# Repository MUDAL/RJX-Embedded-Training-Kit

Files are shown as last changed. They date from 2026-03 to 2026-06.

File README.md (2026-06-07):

# RJX Embedded Training Kit

## Overview  

Hardware training platform built around **STM32L431** with:
- **5 V input** and dual **3.3 V rails** (digital +3V3 and analog +3V3A)
- **Li-ion charger/power-path** + **fuel gauge**
- Sensors (I2C/SMBus + SPI), UI peripherals (LCD/7-seg/buzzer), and **CAN**

This repository contains the complete **KiCad 9** hardware design, PDFs/datasheets, and the STM32CubeMX pinout file. I have ensured that it is properly version-controlled by removing unnecessary KiCad artefacts/tool-specific outputs which can easily be re-generated by any user, and ensuring transition from the schematic design to PCB design and vice-versa without using netlists. The block diagram of the project is shown in the image below.   

<p align="center">
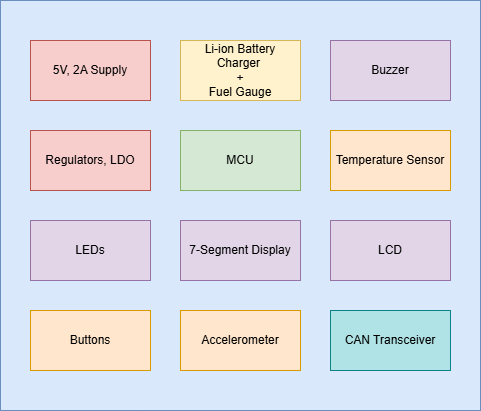
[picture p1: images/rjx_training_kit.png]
    
</p>  

---

## Repository layout

```text
.
├── LICENSE
├── README.md
├── images
│   └── rjx_training_kit.png
├── pinout
│   └── pinout.ioc
└── rjx_training_kit
    ├── Docs         (schematic PDF, datasheets, links)
    ├── Hardware     (KiCad project: schematics + PCB)
    ├── Libs         (project libraries)
    └── Outputs      (manufacturing files)
```

---

## Quick start

### View / edit hardware (KiCad 9)
1. Install **KiCad v9** (recommended).
2. Open the project:
   - `rjx_training_kit/Hardware/rjx_training_kit.kicad_pro`
3. Schematic sheets:
   - Top-level: `rjx_training_kit/Hardware/rjx_training_kit.kicad_sch`
   - Sub-sheets: `rjx_training_kit/Hardware/microcontroller.kicad_sch`, `rjx_training_kit/Hardware/peripherals.kicad_sch`
4. PCB layout:
   - `rjx_training_kit/Hardware/rjx_training_kit.kicad_pcb`

### View pin configuration (STM32CubeMX)
- Open `pinout/pinout.ioc` in **STM32CubeMX**.

---

## Documentation

### Schematic PDF
- `rjx_training_kit/Docs/rjx_training_kit.pdf`

### Component datasheets
Datasheets used by the design are stored in:
- `rjx_training_kit/Docs/`

### External links
External forum references and troubleshooting links are maintained here:
- [Links.md](rjx_training_kit/Docs/Links.md)

---

## Checklist

- [x] Schematic capture  
- [ ] Board setup  
- [ ] Component placement and routing  
- [ ] DRC  
- [ ] Generate manufacturing outputs and BOM   
- [ ] Place an order for the board on PCBWay  
- [ ] Preliminary board tests  
- [ ] Create a basic user guide on how to get started with the board  

## License
GPL-3.0 (see `LICENSE`).

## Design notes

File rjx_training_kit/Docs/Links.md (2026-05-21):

# RJX Training Kit – External Reference Links

This file collects external links (forums, app notes, etc.) so the main README stays concise.

---

## Battery charger (BQ24072/BQ24074) – TI E2E forum threads

1. **Problems in BQ24072**  
   https://e2e.ti.com/support/power-management-group/power-management/f/power-management-forum/106873/problems-in-bq24072

2. **BQ24072: Short circuit condition**  
   https://e2e.ti.com/support/power-management-group/power-management/f/power-management-forum/1271063/bq24072-short-circuit-condition

3. **BQ24072 – low battery behaviour**  
   https://e2e.ti.com/support/power-management-group/power-management/f/power-management-forum/247653/bq24072---low-battery-behaviour

4. **BQ24072 – about battery discharge**  
   https://e2e.ti.com/support/power-management-group/power-management/f/power-management-forum/647933/bq24072-about-battery-discharge-of-bq24072

5. **BQ24072: Charger without battery**  
   https://e2e.ti.com/support/power-management-group/power-management/f/power-management-forum/873241/bq24072-charger-without-battery

6. **BQ24072 – battery removed**  
   https://e2e.ti.com/support/power-management-group/power-management/f/power-management-forum/1407863/bq24072-bq24072---battery-removed

7. **BQ24074: Safety timer**  
   https://e2e.ti.com/support/power-management-group/power-management/f/power-management-forum/1430800/bq24074-safty-timer

8. **BQ24074: Safety timer**  
   https://e2e.ti.com/support/power-management-group/power-management/f/power-management-forum/787195/bq24074-safety-timer

9. **BQ24072 – current setting calculations**  
   https://e2e.ti.com/support/power-management-group/power-management/f/power-management-forum/393015/bq24072---current-setting-calculations

10. **BQ24072 – input current set is 1.5 A, charging current is set to 0.4 A**  
    https://e2e.ti.com/support/power-management-group/power-management/f/power-management-forum/685457/bq24072-input-current-set-is-1-5amps-charging-current-is-set-to-0-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

11. **BQ24072 – setting current limit**  
    https://e2e.ti.com/support/power-management-group/power-management/f/power-management-forum/65275/bq24072---setting-current-limit

---

## LDO / power-good (PG)

12. **ST forum – Power good (PG) pin on LD39100** *(related discussion for PG behavior)*  
    https://community.st.com/t5/power-management/power-good-pg-pin-on-ld39100/td-p/641594

---

## Extra resources  

13. **Electronics StackExchange - Difference between crystal oscillators and resonators**  
   https://electronics.stackexchange.com/questions/36308/crystals-oscillators-and-resonators-what-the-difference/36321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

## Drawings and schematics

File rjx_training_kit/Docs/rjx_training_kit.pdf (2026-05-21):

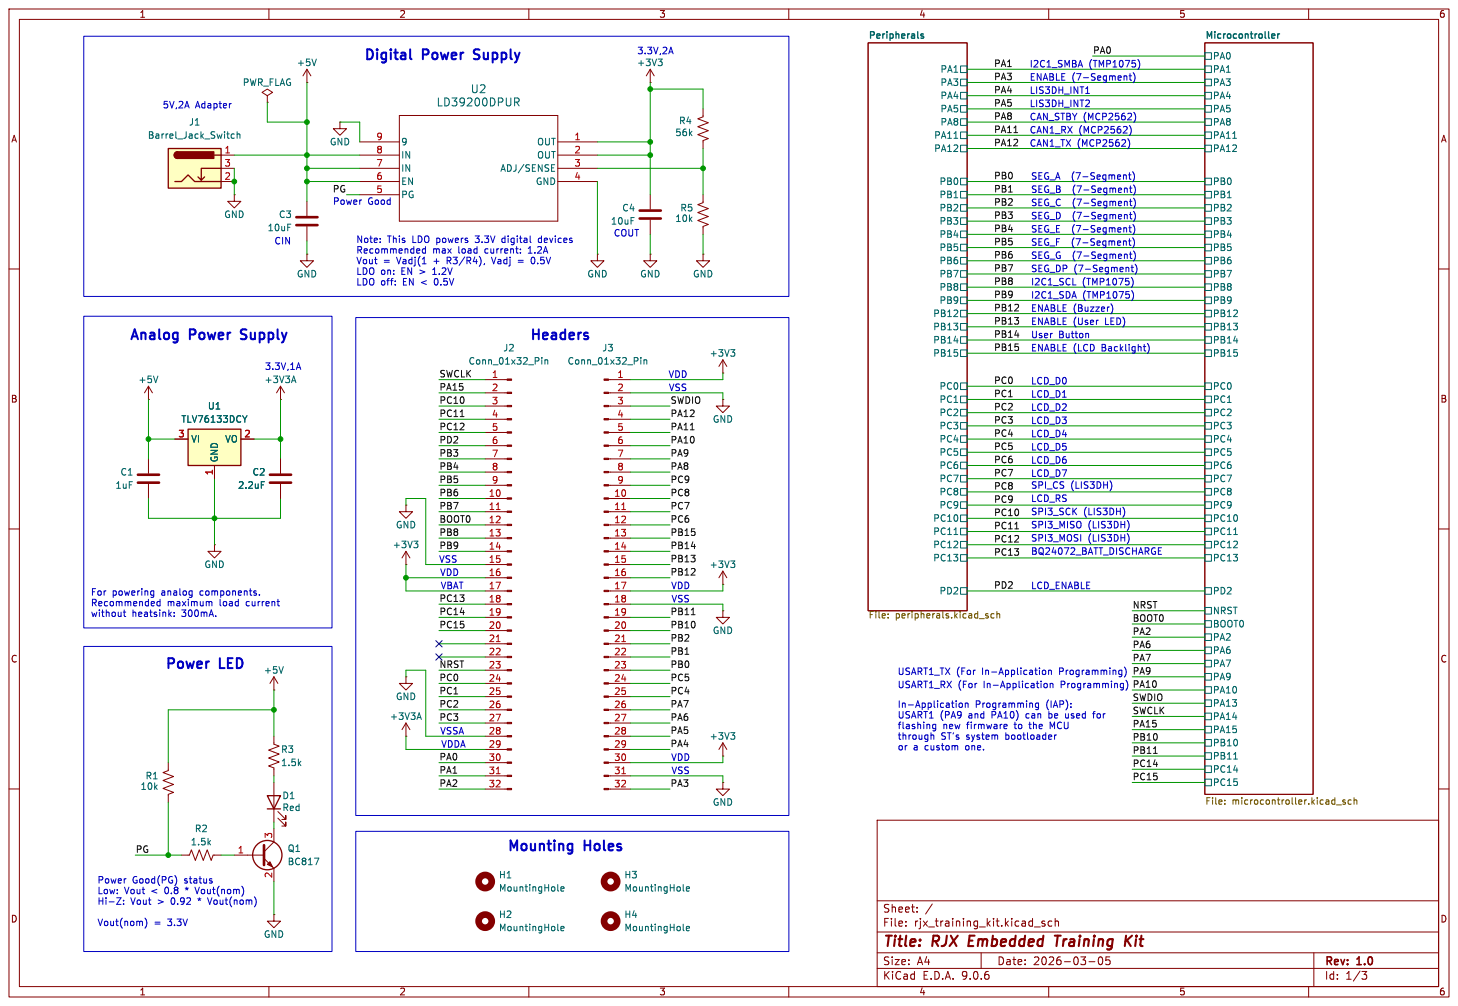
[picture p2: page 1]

LCD_D3 ENABLE (LCD Backlight) User Button

Id: 1/3 Title: RJX Embedded Training Kit File: rjx_training_kit.kicad_sch Sheet: /

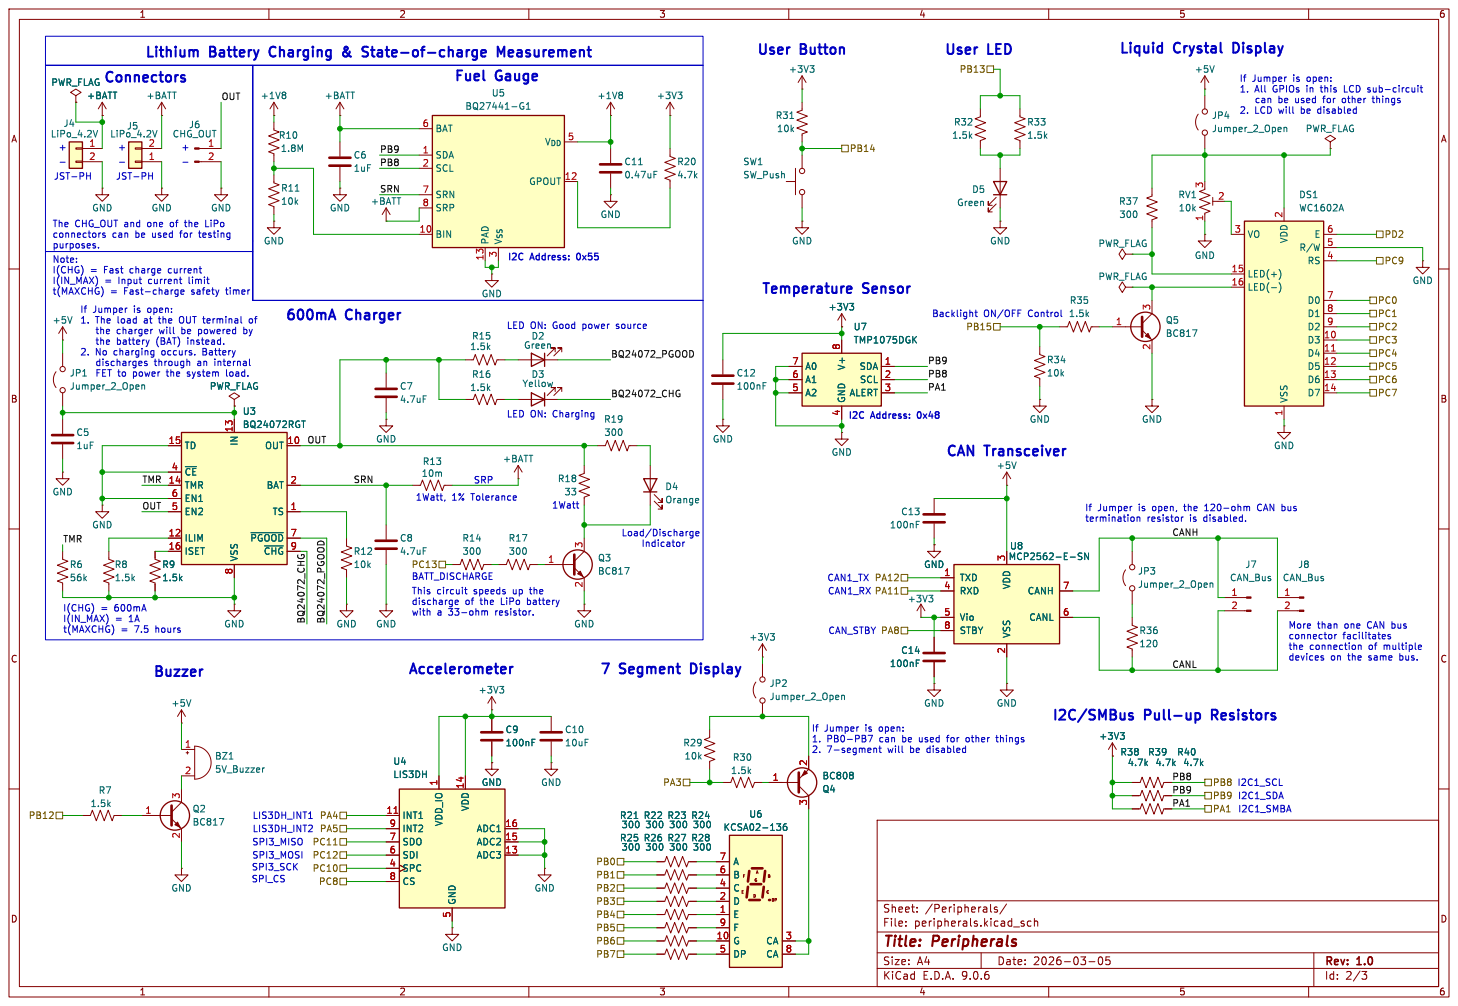
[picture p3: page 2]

Fuel Gauge
If Jumper is open: 1. All GPIOs in this LCD sub-circuit can be used for other things 2. LCD will be disabled SRP

The CHG_OUT and one of the LiPo
I(CHG) = Fast charge current
I(IN_MAX) = Input current limit

4 SDA 1 SCL 2 ALERT 3 U7 TMP1075DGK R7
the charger will be powered by

LED ON: Good power source BATT_DISCHARGE

8 OUT 10 BAT 2 TS 1 ~{PGOOD}7 ~{CHG}9 U3BQ24072RGT PWR_FLAG

8 OUT 10 BAT 2 TS 1 ~{PGOOD}7 ~{CHG}9 PWR_FLAG

File: peripherals.kicad_sch Sheet: /Peripherals/ GND

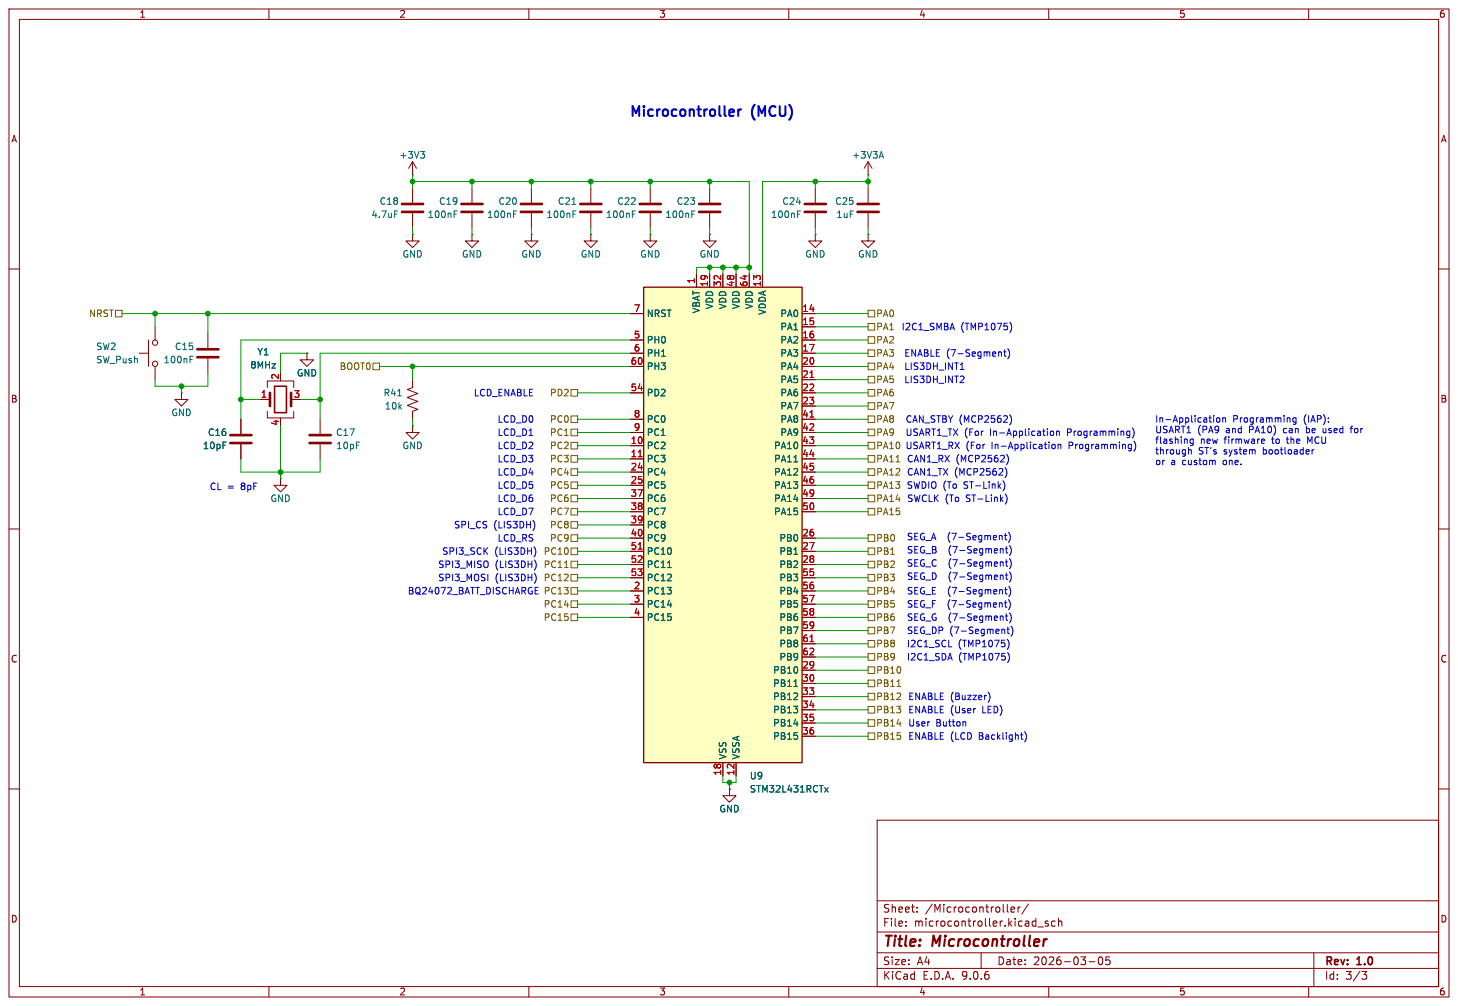
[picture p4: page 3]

I2C1_SCL (TMP1075) ENABLE (LCD Backlight) ENABLE (Buzzer) ENABLE (User LED) ENABLE (7-Segment)

1 VDD 19 VDD 32 VSS 18 VDD 48 VSSA 12 VDD 64 VDDA 13 PA0 14 PA1 15 PA2 16 PA3 17 PA4 20 PA5 21 PA6 22 PA7 23 PA8 41 PA9 42 PA10 43 PA11 44 PA12 45 PA13 46 PA14 49 PA15 50 PB0 26 PB1 27 PB2 28 PB3 55 PB4 56 PB5 57 PB6 58 PB7 59 PB8 61 PB9 62 PB10 29 PB11 30 PB12 33 PB13 34 PB14 35 PB15 36 C16

1 VDD 19 VDD 32 VSS 18 VDD 48 VSSA 12 VDD 64 VDDA 13 PA0 14 PA1 15 PA2 16 PA3 17 PA4 20 PA5 21 PA6 22 PA7 23 PA8 41 PA9 42 PA10 43 PA11 44 PA12 45 PA13 46 PA14 49 PA15 50 PB0 26 PB1 27 PB2 28 PB3 55 PB4 56 PB5 57 PB6 58 PB7 59 PB8 61 PB9 62 PB10 29 PB11 30 PB12 33 PB13 34 PB14 35 PB15 36 U9STM32L431RCTx

I2C1_SMBA (TMP1075) SWDIO (To ST-Link) SPI3_MOSI (LIS3DH) SPI3_SCK (LIS3DH) BQ24072_BATT_DISCHARGE

Id: 3/3 Title: Microcontroller File: microcontroller.kicad_sch Sheet: /Microcontroller/ GND

through ST's system bootloader or a custom one.

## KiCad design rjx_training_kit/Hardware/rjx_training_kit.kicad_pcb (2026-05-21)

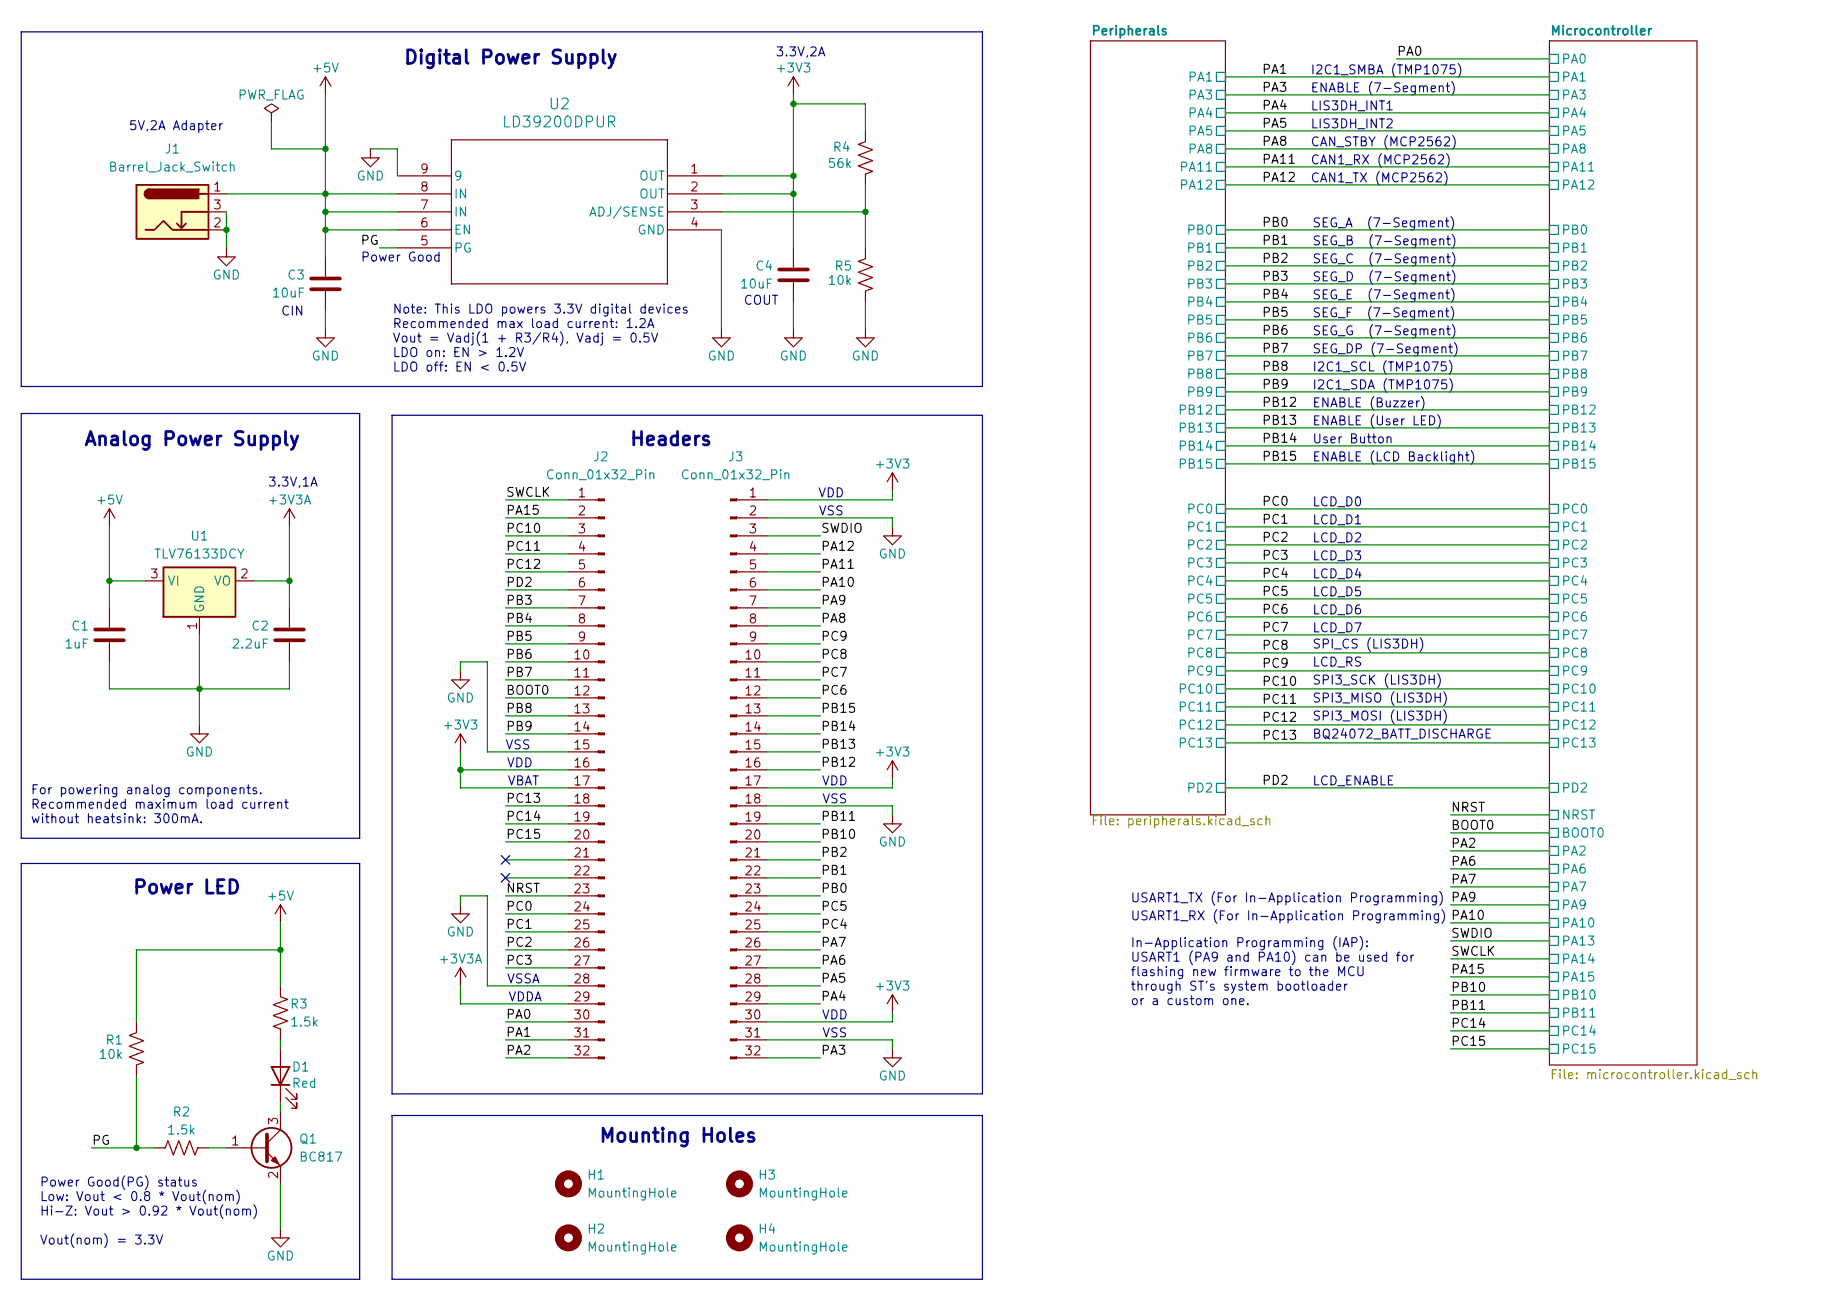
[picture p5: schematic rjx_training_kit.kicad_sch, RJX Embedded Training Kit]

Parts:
C1: 1uF; C_0603_1608Metric
C2: 2.2uF; C_0603_1608Metric
C3, C4: 10uF; C_0603_1608Metric
D1: Red; LED_0603_1608Metric
H1, H2, H3, H4: MountingHole; MountingHole_3mm
J1: Barrel_Jack_Switch; BarrelJack_Horizontal
J2, J3: Conn_01x32_Pin; PinHeader_1x32_P2.54mm_Vertical
Q1: BC817; SOT-23
R1, R5: 10k; R_0603_1608Metric
R2, R3: 1.5k; R_0603_1608Metric
R4: 56k; R_0603_1608Metric
U1: TLV76133DCY; SOT-223-3_TabPin2
U2: LD39200DPUR; DFN-8-1EP_4x4mm_P0.8mm_EP2.3x3.24mm

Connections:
+3V3: C4.1, J2.16, J2.17, J3.1, J3.17, J3.30, R4.2, U2.1 (OUT), U2.2 (OUT); also elsewhere on the board
+3V3A: C2.1, J2.29, U1.2 (VO); also elsewhere on the board
+5V: C1.1, C3.1, J1.1, R1.2, R3.1, U1.3 (VI), U2.6 (EN), U2.7 (IN), U2.8 (IN); also elsewhere on the board
/BOOT0: J2.12; also elsewhere on the board
/NRST: J2.23; also elsewhere on the board
/PA0: J2.30; also elsewhere on the board
/PA1: J2.31; also elsewhere on the board
/PA2: J2.32; also elsewhere on the board
/PA3: J3.32; also elsewhere on the board
/PA4: J3.29; also elsewhere on the board
/PA5: J3.28; also elsewhere on the board
/PA6: J3.27; also elsewhere on the board
/PA7: J3.26; also elsewhere on the board
/PA8: J3.8; also elsewhere on the board
/PA9: J3.7; also elsewhere on the board
/PA10: J3.6; also elsewhere on the board
/PA11: J3.5; also elsewhere on the board
/PA12: J3.4; also elsewhere on the board
/PA15: J2.2; also elsewhere on the board
/PB0: J3.23; also elsewhere on the board
/PB1: J3.22; also elsewhere on the board
/PB2: J3.21; also elsewhere on the board
/PB3: J2.7; also elsewhere on the board
/PB4: J2.8; also elsewhere on the board
/PB5: J2.9; also elsewhere on the board
/PB6: J2.10; also elsewhere on the board
/PB7: J2.11; also elsewhere on the board
/PB8: J2.13; also elsewhere on the board
/PB9: J2.14; also elsewhere on the board
/PB10: J3.20; also elsewhere on the board
/PB11: J3.19; also elsewhere on the board
/PB12: J3.16; also elsewhere on the board
/PB13: J3.15; also elsewhere on the board
/PB14: J3.14; also elsewhere on the board
/PB15: J3.13; also elsewhere on the board
/PC0: J2.24; also elsewhere on the board
/PC1: J2.25; also elsewhere on the board
/PC2: J2.26; also elsewhere on the board
/PC3: J2.27; also elsewhere on the board
/PC4: J3.25; also elsewhere on the board
/PC5: J3.24; also elsewhere on the board
/PC6: J3.12; also elsewhere on the board
/PC7: J3.11; also elsewhere on the board
/PC8: J3.10; also elsewhere on the board
/PC9: J3.9; also elsewhere on the board
/PC10: J2.3; also elsewhere on the board
/PC11: J2.4; also elsewhere on the board
/PC12: J2.5; also elsewhere on the board
/PC13: J2.18; also elsewhere on the board
/PC14: J2.19; also elsewhere on the board
/PC15: J2.20; also elsewhere on the board
/PD2: J2.6; also elsewhere on the board
/PG: R1.1, R2.1, U2.5 (PG)
/SWCLK: J2.1; also elsewhere on the board
/SWDIO: J3.3; also elsewhere on the board
GND: C1.2, C2.2, C3.2, C4.2, J1.2, J1.3, J2.15, J2.28, J3.2, J3.18, J3.31, Q1.2 (E), R5.1, U1.1 (GND), U2.4 (GND), U2.9; also elsewhere on the board
unnamed: D1.2 (A), R3.2
unnamed: D1.1 (K), Q1.3 (C)
unnamed: Q1.1 (B), R2.2
unnamed: R4.1, R5.2, U2.3 (ADJ/SENSE)

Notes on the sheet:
SPI3_SCK (LIS3DH)
For powering analog components. Recommended maximum load current without heatsink: 300mA.
Mounting Holes
SEG_C (7-Segment)
COUT
VSS
Power Good(PG) status Low: Vout < 0.8 * Vout(nom) Hi-Z: Vout > 0.92 * Vout(nom) Vout(nom) = 3.3V
CAN_STBY (MCP2562)
I2C1_SDA (TMP1075)
ENABLE (7-Segment)
SEG_B (7-Segment)
Analog Power Supply
LIS3DH_INT2
ENABLE (Buzzer)
LCD_D0
VDDA
I2C1_SMBA (TMP1075)
3.3V,1A
LCD_D7
SPI3_MOSI (LIS3DH)
SEG_F (7-Segment)
LCD_D3
LCD_RS
LCD_D4
ENABLE (LCD Backlight)
LCD_D5
VDD
CIN
SEG_G (7-Segment)
User Button
Digital Power Supply
I2C1_SCL (TMP1075)
LCD_D1
5V,2A Adapter
SEG_DP (7-Segment)
LCD_D2
VSSA
3.3V,2A
USART1_TX (For In-Application Programming)
VBAT

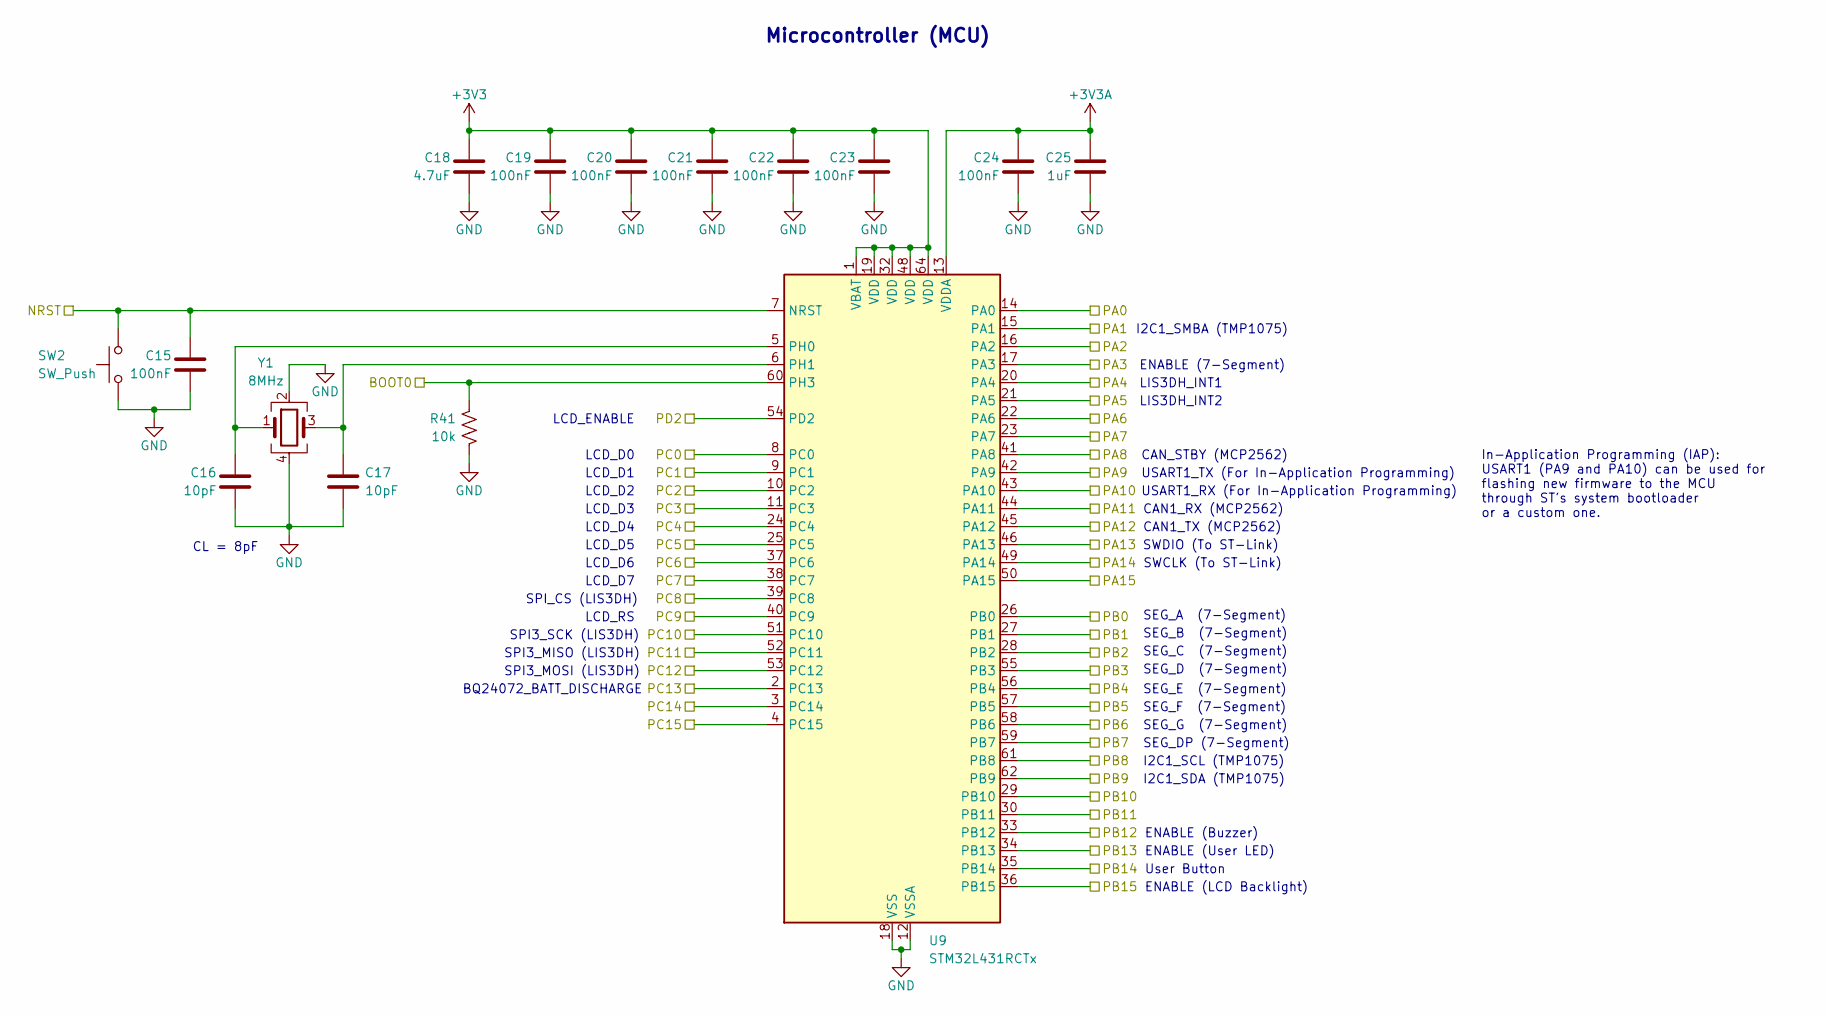
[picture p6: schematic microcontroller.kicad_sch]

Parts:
C15, C19, C20, C21, C22, C23, C24: 100nF; C_0603_1608Metric
C16, C17: 10pF; C_0603_1608Metric
C18: 4.7uF; C_0603_1608Metric
C25: 1uF; C_0603_1608Metric
R41: 10k; R_0603_1608Metric
SW2: SW_Push; SW_PUSH_6mm
U9: STM32L431RCTx; LQFP-64_10x10mm_P0.5mm
Y1: 8MHz; Crystal_SMD_3225-4Pin_3.2x2.5mm

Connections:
+3V3: C18.1, C19.1, C20.1, C21.1, C22.1, C23.1, U9.1 (VBAT), U9.19 (VDD), U9.32 (VDD), U9.48 (VDD), U9.64 (VDD); also elsewhere on the board
+3V3A: C24.1, C25.1, U9.13 (VDDA); also elsewhere on the board
/BOOT0: R41.1, U9.60 (PH3); also elsewhere on the board
/NRST: C15.1, SW2.2, U9.7 (NRST); also elsewhere on the board
/PA0: U9.14 (PA0); also elsewhere on the board
/PA1: U9.15 (PA1); also elsewhere on the board
/PA2: U9.16 (PA2); also elsewhere on the board
/PA3: U9.17 (PA3); also elsewhere on the board
/PA4: U9.20 (PA4); also elsewhere on the board
/PA5: U9.21 (PA5); also elsewhere on the board
/PA6: U9.22 (PA6); also elsewhere on the board
/PA7: U9.23 (PA7); also elsewhere on the board
/PA8: U9.41 (PA8); also elsewhere on the board
/PA9: U9.42 (PA9); also elsewhere on the board
/PA10: U9.43 (PA10); also elsewhere on the board
/PA11: U9.44 (PA11); also elsewhere on the board
/PA12: U9.45 (PA12); also elsewhere on the board
/PA15: U9.50 (PA15); also elsewhere on the board
/PB0: U9.26 (PB0); also elsewhere on the board
/PB1: U9.27 (PB1); also elsewhere on the board
/PB2: U9.28 (PB2); also elsewhere on the board
/PB3: U9.55 (PB3); also elsewhere on the board
/PB4: U9.56 (PB4); also elsewhere on the board
/PB5: U9.57 (PB5); also elsewhere on the board
/PB6: U9.58 (PB6); also elsewhere on the board
/PB7: U9.59 (PB7); also elsewhere on the board
/PB8: U9.61 (PB8); also elsewhere on the board
/PB9: U9.62 (PB9); also elsewhere on the board
/PB10: U9.29 (PB10); also elsewhere on the board
/PB11: U9.30 (PB11); also elsewhere on the board
/PB12: U9.33 (PB12); also elsewhere on the board
/PB13: U9.34 (PB13); also elsewhere on the board
/PB14: U9.35 (PB14); also elsewhere on the board
/PB15: U9.36 (PB15); also elsewhere on the board
/PC0: U9.8 (PC0); also elsewhere on the board
/PC1: U9.9 (PC1); also elsewhere on the board
/PC2: U9.10 (PC2); also elsewhere on the board
/PC3: U9.11 (PC3); also elsewhere on the board
/PC4: U9.24 (PC4); also elsewhere on the board
/PC5: U9.25 (PC5); also elsewhere on the board
/PC6: U9.37 (PC6); also elsewhere on the board
/PC7: U9.38 (PC7); also elsewhere on the board
/PC8: U9.39 (PC8); also elsewhere on the board
/PC9: U9.40 (PC9); also elsewhere on the board
/PC10: U9.51 (PC10); also elsewhere on the board
/PC11: U9.52 (PC11); also elsewhere on the board
/PC12: U9.53 (PC12); also elsewhere on the board
/PC13: U9.2 (PC13); also elsewhere on the board
/PC14: U9.3 (PC14); also elsewhere on the board
/PC15: U9.4 (PC15); also elsewhere on the board
/PD2: U9.54 (PD2); also elsewhere on the board
/SWCLK: U9.49 (PA14); also elsewhere on the board
/SWDIO: U9.46 (PA13); also elsewhere on the board
GND: C15.2, C16.2, C17.2, C18.2, C19.2, C20.2, C21.2, C22.2, C23.2, C24.2, C25.2, R41.2, SW2.1, U9.12 (VSSA), U9.18 (VSS), U9.31 (VSS), U9.47 (VSS), U9.63 (VSS), Y1.2, Y1.4; also elsewhere on the board
unnamed: C16.1, U9.5 (PH0), Y1.1
unnamed: C17.1, U9.6 (PH1), Y1.3

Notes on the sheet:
SPI3_MOSI (LIS3DH)
SWCLK (To ST-Link)
CAN1_RX (MCP2562)
SPI_CS (LIS3DH)
SEG_C (7-Segment)
ENABLE (User LED)
Microcontroller (MCU)
USART1_RX (For In-Application Programming)
LCD_ENABLE
USART1_TX (For In-Application Programming)
LIS3DH_INT2
ENABLE (Buzzer)
LCD_D5
ENABLE (LCD Backlight)
CAN1_TX (MCP2562)
SEG_B (7-Segment)
SPI3_SCK (LIS3DH)
LIS3DH_INT1
SWDIO (To ST-Link)
LCD_D0
LCD_D6
BQ24072_BATT_DISCHARGE
In-Application Programming (IAP): USART1 (PA9 and PA10) can be used for flashing new firmware to the MCU through ST's system bootloader or a custom one.
SEG_D (7-Segment)
SEG_DP (7-Segment)
ENABLE (7-Segment)
CL = 8pF
SEG_E (7-Segment)
LCD_RS
LCD_D4
LCD_D2
CAN_STBY (MCP2562)
I2C1_SCL (TMP1075)
I2C1_SMBA (TMP1075)
LCD_D3
SEG_G (7-Segment)
LCD_D7
User Button
SPI3_MISO (LIS3DH)
LCD_D1

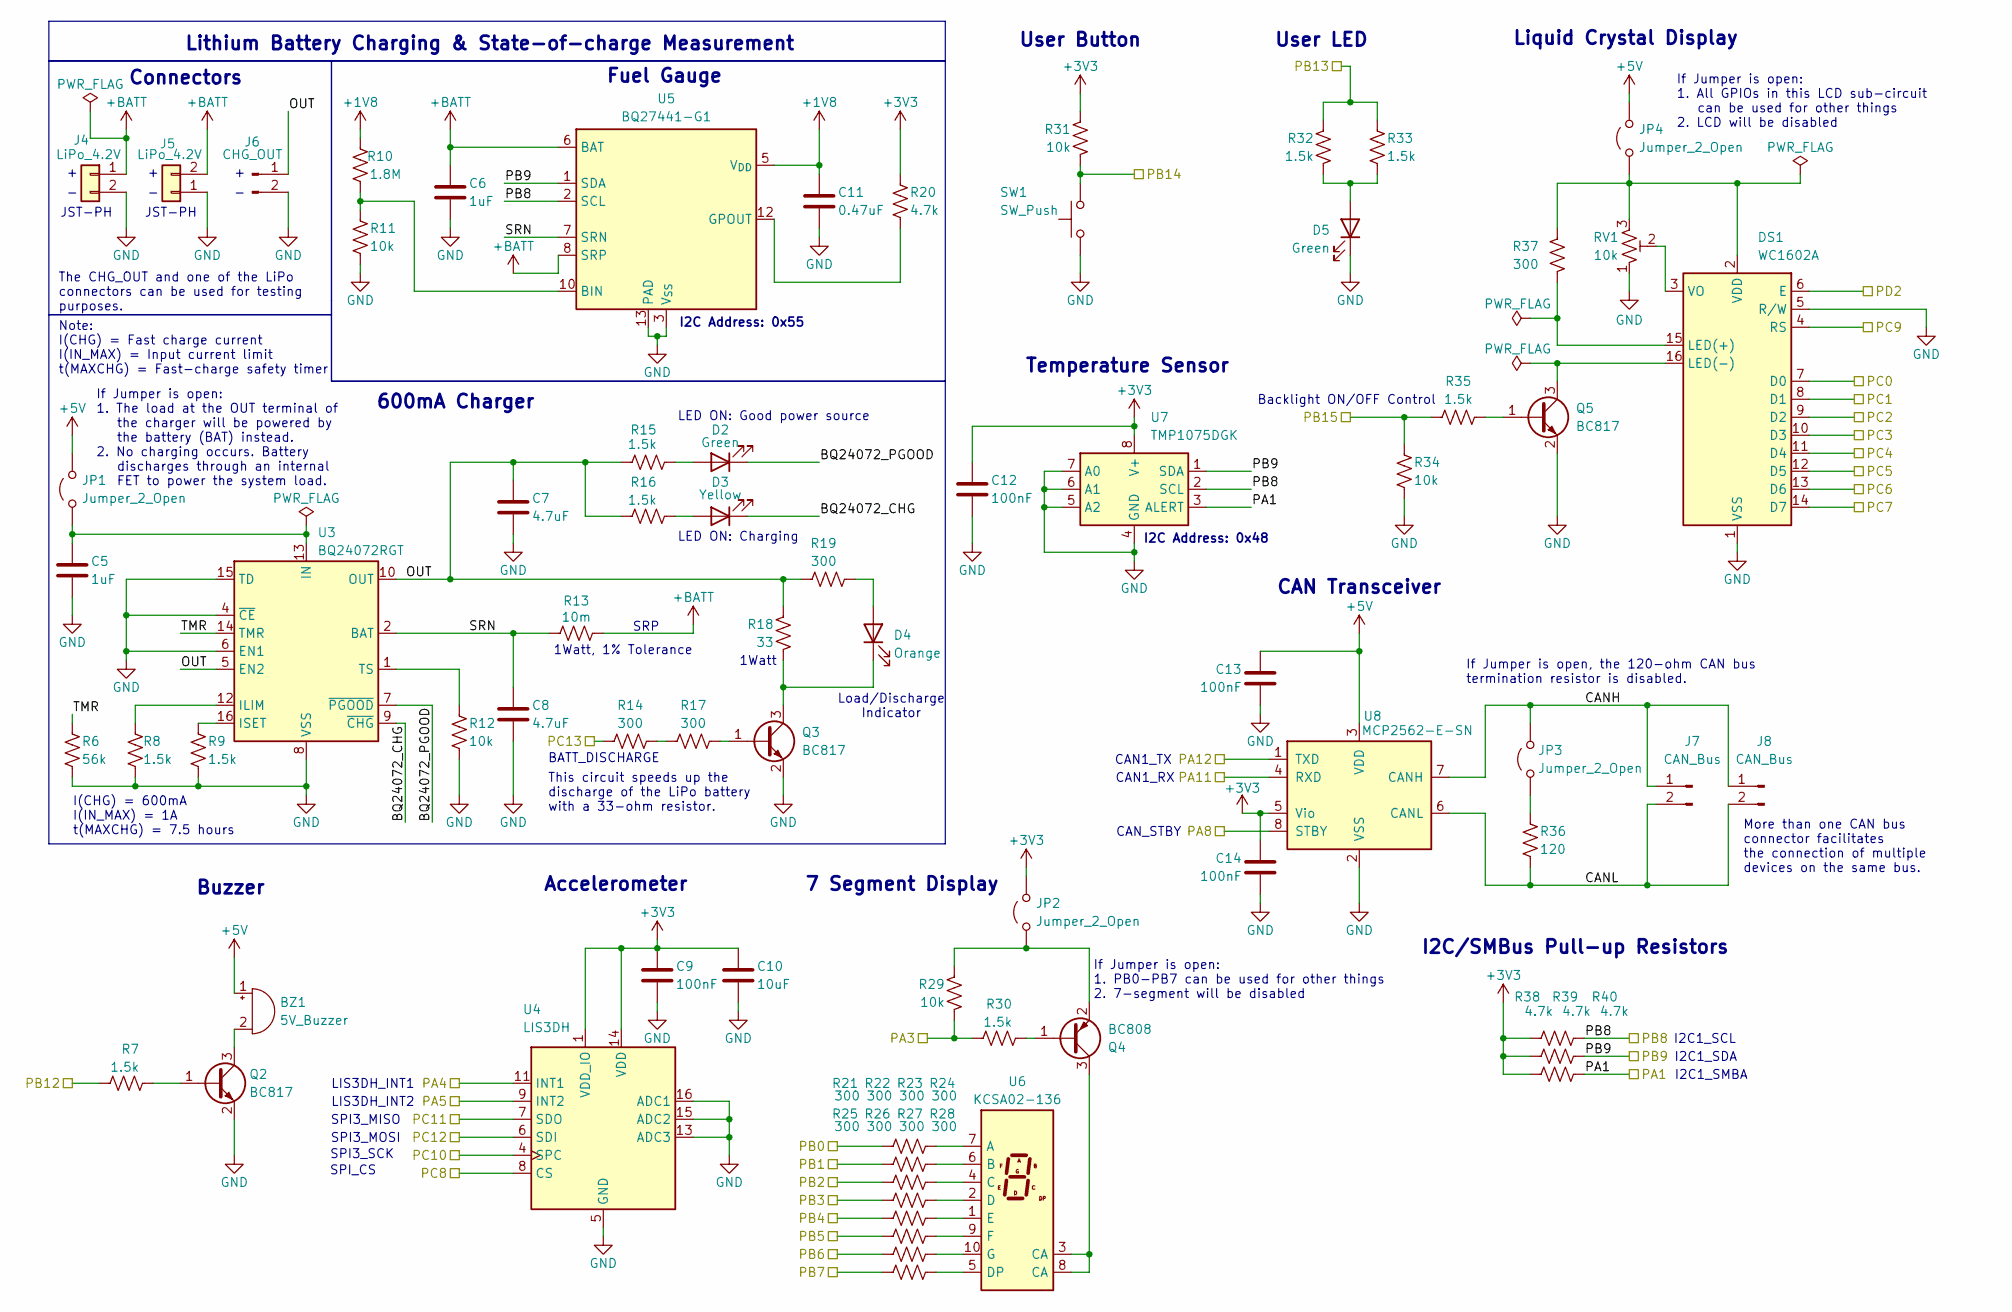
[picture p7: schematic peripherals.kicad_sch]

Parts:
BZ1: 5V_Buzzer; Buzzer_12x9.5RM7.6
C5, C6: 1uF; C_0603_1608Metric
C7, C8: 4.7uF; C_0603_1608Metric
C9, C12, C13, C14: 100nF; C_0603_1608Metric
C10: 10uF; C_0603_1608Metric
C11: 0.47uF; C_0603_1608Metric
D2, D5: Green; LED_0603_1608Metric
D3: Yellow; LED_0603_1608Metric
D4: Orange; LED_0603_1608Metric
DS1: WC1602A; PinSocket_1x16_P2.54mm_Vertical
J4, J5: LiPo_4.2V; JST_PH_S2B-PH-K_1x02_P2.00mm_Horizontal
J6: CHG_OUT; PinHeader_1x02_P2.54mm_Vertical
J7, J8: CAN_Bus; PinHeader_1x02_P2.54mm_Vertical
JP1, JP2, JP3, JP4: Jumper_2_Open; PinHeader_1x02_P2.54mm_Vertical
Q2, Q3, Q5: BC817; SOT-23
Q4: BC808; SOT-23
R6: 56k; R_0603_1608Metric
R7, R8, R9, R15, R16, R30, R32, R33, R35: 1.5k; R_0603_1608Metric
R10: 1.8M; R_0603_1608Metric
R11, R12, R29, R31, R34: 10k; R_0603_1608Metric
R13: 10m; R_2512_6332Metric
R14, R17, R19, R21, R22, R23, R24, R25, R26, R27, R28, R37: 300; R_0603_1608Metric
R18: 33; R_2512_6332Metric
R20, R38, R39, R40: 4.7k; R_0603_1608Metric
R36: 120; R_0603_1608Metric
RV1: 10k; Potentiometer_Bourns_3296W_Vertical
SW1: SW_Push; SW_PUSH_6mm
U3: BQ24072RGT; VQFN-16-1EP_3x3mm_P0.5mm_EP1.6x1.6mm
U4: LIS3DH; LGA-16_3x3mm_P0.5mm_LayoutBorder3x5y
U5: BQ27441-G1; Texas_S-PDSO-N12
U6: KCSA02-136; KCSC02-136
U7: TMP1075DGK; VSSOP-8_3x3mm_P0.65mm
U8: MCP2562-E-SN; SOIC-8_3.9x4.9mm_P1.27mm

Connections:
+1V8: C11.1, R10.1, U5.5 (V_{DD})
+3V3: C9.1, C10.1, C12.1, C14.1, JP2.2 (B), R20.1, R31.1, R38.1, R39.1, R40.1, U4.1 (VDD_IO), U4.14 (VDD), U7.8 (V+), U8.5 (Vio); also elsewhere on the board
+5V: BZ1.1 (+), C13.1, JP1.2 (B), JP4.2 (B), U8.3 (VDD); also elsewhere on the board
+BATT: C6.1, J4.1, J5.2, R13.2, U5.6 (BAT), U5.8 (SRP)
/PA1: R40.2, U7.3 (ALERT); also elsewhere on the board
/PA3: R29.2, R30.1; also elsewhere on the board
/PA4: U4.11 (INT1); also elsewhere on the board
/PA5: U4.9 (INT2); also elsewhere on the board
/PA8: U8.8 (STBY); also elsewhere on the board
/PA11: U8.4 (RXD); also elsewhere on the board
/PA12: U8.1 (TXD); also elsewhere on the board
/PB0: R21.1; also elsewhere on the board
/PB1: R22.1; also elsewhere on the board
/PB2: R23.1; also elsewhere on the board
/PB3: R24.1; also elsewhere on the board
/PB4: R25.1; also elsewhere on the board
/PB5: R26.1; also elsewhere on the board
/PB6: R27.1; also elsewhere on the board
/PB7: R28.1; also elsewhere on the board
/PB8: R38.2, U5.2 (SCL), U7.2 (SCL); also elsewhere on the board
/PB9: R39.2, U5.1 (SDA), U7.1 (SDA); also elsewhere on the board
/PB12: R7.1; also elsewhere on the board
/PB13: R32.1, R33.1; also elsewhere on the board
/PB14: R31.2, SW1.2; also elsewhere on the board
/PB15: R34.1, R35.1; also elsewhere on the board
/PC0: DS1.7 (D0); also elsewhere on the board
/PC1: DS1.8 (D1); also elsewhere on the board
/PC2: DS1.9 (D2); also elsewhere on the board
/PC3: DS1.10 (D3); also elsewhere on the board
/PC4: DS1.11 (D4); also elsewhere on the board
/PC5: DS1.12 (D5); also elsewhere on the board
/PC6: DS1.13 (D6); also elsewhere on the board
/PC7: DS1.14 (D7); also elsewhere on the board
/PC8: U4.8 (CS); also elsewhere on the board
/PC9: DS1.4 (RS); also elsewhere on the board
/PC10: U4.4 (SPC); also elsewhere on the board
/PC11: U4.7 (SDO); also elsewhere on the board
/PC12: U4.6 (SDI); also elsewhere on the board
/PC13: R14.1; also elsewhere on the board
/PD2: DS1.6 (E); also elsewhere on the board
/Peripherals/BQ24072_CHG: D3.1 (K), U3.9 (~CHG)
/Peripherals/BQ24072_PGOOD: D2.1 (K), U3.7 (~PGOOD)
/Peripherals/CANH: J7.1, J8.1, JP3.2 (B), U8.7 (CANH)
/Peripherals/CANL: J7.2, J8.2, R36.2, U8.6 (CANL)
/Peripherals/OUT: C7.1, J6.1, R15.1, R16.1, R18.1, R19.1, U3.5 (EN2), U3.10 (OUT), U3.11 (OUT)
/Peripherals/SRN: C8.1, R13.1, U3.2 (BAT), U3.3 (BAT), U5.7 (SRN)
/Peripherals/TMR: R6.1, U3.14 (TMR)
GND: C5.2, C6.2, C7.2, C8.2, C9.2, C10.2, C11.2, C12.2, C13.2, C14.2, D5.1 (K), DS1.1 (VSS), DS1.5 (R/W), J4.2, J5.1, J6.2, Q2.2 (E), Q3.2 (E), Q5.2 (E), R6.2, R8.2, R9.2, R11.2, R12.2, R34.2, RV1.1, SW1.1, U3.4 (~CE), U3.6 (EN1), U3.8 (VSS), U3.15 (TD), U3.17 (VSS), U4.5 (GND), U4.10 (GND), U4.12 (GND), U4.13 (ADC3), U4.15 (ADC2), U4.16 (ADC1), U5.3 (V_{SS}), U5.13 (PAD), U7.4 (GND), U7.5 (A2), U7.6 (A1), U7.7 (A0), U8.2 (VSS); also elsewhere on the board
unnamed: BZ1.2 (-), Q2.3 (C)
unnamed: D2.2 (A), R15.2
unnamed: D3.2 (A), R16.2
unnamed: D4.2 (A), R19.2
unnamed: D4.1 (K), Q3.3 (C), R18.2
unnamed: D5.2 (A), R32.2, R33.2
unnamed: DS1.15 (LED(+)), R37.1
unnamed: DS1.16 (LED(-)), Q5.3 (C)
unnamed: DS1.2 (VDD), JP4.1 (A), R37.2, RV1.3
unnamed: DS1.3 (VO), RV1.2
unnamed: C5.1, JP1.1 (A), U3.13 (IN)
unnamed: JP2.1 (A), Q4.2 (E), R29.1
unnamed: JP3.1 (A), R36.1
unnamed: Q2.1 (B), R7.2
unnamed: Q3.1 (B), R17.2
unnamed: Q4.1 (B), R30.2
unnamed: Q4.3 (C), U6.3 (CA), U6.8 (CA)
unnamed: Q5.1 (B), R35.2
unnamed: R14.2, R17.1
unnamed: R8.1, U3.12 (ILIM)
unnamed: R9.1, U3.16 (ISET)
unnamed: R12.1, U3.1 (TS)
unnamed: R10.2, R11.1, U5.10 (BIN)
unnamed: R20.2, U5.12 (GPOUT)
unnamed: R21.2, U6.7 (A)
unnamed: R22.2, U6.6 (B)
unnamed: R23.2, U6.4 (C)
unnamed: R24.2, U6.2 (D)
unnamed: R28.2, U6.5 (DP)
unnamed: R25.2, U6.1 (E)
unnamed: R26.2, U6.9 (F)
unnamed: R27.2, U6.10 (G)

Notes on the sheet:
If Jumper is open: 1. All GPIOs in this LCD sub-circuit can be used for other things 2. LCD will be disabled
SPI3_MISO
Liquid Crystal Display
If Jumper is open: 1. The load at the OUT terminal of the charger will be powered by the battery (BAT) instead. 2. No charging occurs. Battery discharges through an internal FET to power the system load.
I2C Address: 0x55
CAN1_TX
SPI3_SCK
User Button
I2C/SMBus Pull-up Resistors
JST-PH
I2C Address: 0x48
CAN_STBY
Lithium Battery Charging & State-of-charge Measurement
This circuit speeds up the discharge of the LiPo battery with a 33-ohm resistor.
Note: I(CHG) = Fast charge current I(IN_MAX) = Input current limit t(MAXCHG) = Fast-charge safety timer
600mA Charger
Buzzer
I2C1_SMBA
User LED
LED ON: Good power source
I2C1_SCL
LIS3DH_INT1
I2C1_SDA
SRP
Load/Discharge Indicator
Temperature Sensor
SPI3_MOSI
SPI_CS
I(CHG) = 600mA I(IN_MAX) = 1A t(MAXCHG) = 7.5 hours
More than one CAN bus connector facilitates the connection of multiple devices on the same bus.
CAN Transceiver
Accelerometer
Connectors
1Watt, 1% Tolerance
7 Segment Display
Backlight ON/OFF Control
If Jumper is open, the 120-ohm CAN bus termination resistor is disabled.
1Watt
LED ON: Charging
If Jumper is open: 1. PB0-PB7 can be used for other things 2. 7-segment will be disabled

Board: 2 copper layers, 107 parts (0 on the bottom side), 103 nets, no tracks yet.

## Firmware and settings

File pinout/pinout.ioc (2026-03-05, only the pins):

Mcu.UserName=STM32L431RCTx
PA1.Signal=I2C1_SMBA
PA10.Signal=USART1_RX
PA11.Signal=CAN1_RX
PA12.Signal=CAN1_TX
PA2.Signal=USART2_TX
PA3.GPIO_Label=SEGMENT_ENABLE
PA3.Signal=GPIO_Output
PA4.GPIO_Label=LIS3DH_INT1
PA4.Signal=GPIO_Input
PA5.GPIO_Label=LIS3DH_INT2
PA5.Signal=GPIO_Input
PA8.GPIO_Label=CAN_STBY
PA8.Signal=GPIO_Output
PA9.Signal=USART1_TX
PB0.GPIO_Label=SEG_A
PB0.Signal=GPIO_Output
PB1.GPIO_Label=SEG_B
PB1.Signal=GPIO_Output
PB10.Signal=I2C2_SCL
PB11.Signal=I2C2_SDA
PB12.GPIO_Label=BUZZER
PB12.Signal=GPIO_Output
PB13.GPIO_Label=USER_LED
PB13.Signal=GPIO_Output
PB14.GPIO_Label=USER_BUTTON
PB14.Signal=GPIO_Input
PB15.GPIO_Label=LCD_BACKLIGHT
PB15.Signal=GPIO_Output
PB2.GPIO_Label=SEG_C
PB2.Signal=GPIO_Output
PB5.GPIO_Label=SEG_F
PB5.Signal=GPIO_Output
PB6.GPIO_Label=SEG_G
PB6.Signal=GPIO_Output
PB7.GPIO_Label=SEG_DP
PB7.Signal=GPIO_Output
PB8.Signal=I2C1_SCL
PB9.Signal=I2C1_SDA
PC0.GPIO_Label=LCD_D0
PC0.Signal=GPIO_Output
PC1.GPIO_Label=LCD_D1
PC1.Signal=GPIO_Output
PC10.Signal=SPI3_SCK
PC11.Signal=SPI3_MISO
PC12.Signal=SPI3_MOSI
PC13.GPIO_Label=BATTERY_DISCHARGE
PC13.Signal=GPIO_Output
PC2.GPIO_Label=LCD_D2
PC2.Signal=GPIO_Output
PC3.GPIO_Label=LCD_D3
PC3.Signal=GPIO_Output
PC4.GPIO_Label=LCD_D4
PC4.Signal=GPIO_Output
PC5.GPIO_Label=LCD_D5
PC5.Signal=GPIO_Output
PC6.GPIO_Label=LCD_D6
PC6.Signal=GPIO_Output
PC7.GPIO_Label=LCD_D7
PC7.Signal=GPIO_Output
PC8.GPIO_Label=SPI_CS
PC8.Signal=GPIO_Output
PC9.GPIO_Label=LCD_RS
PC9.Signal=GPIO_Output
PD2.GPIO_Label=LCD_EN
PD2.Signal=GPIO_Output

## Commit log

2026-03-04 [RJX]: New project structure
    [microcontroller.kicad_sch, peripherals.kicad_sch, rjx_training_kit.kicad_pcb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]
2026-03-05 [RJX]: Label for PA0 no longer needed
    [pinout.ioc]
2026-03-05 [RJX]: Removed SRP label to eliminate annoying KiCad warning. This warning shows up because the SRP label is connected to +BATT.
    [peripherals.kicad_sch]
2026-03-05 [RJX]: Schematic PDF update
2026-03-05 [RJX]: Changed the dates on the title blocks of all schematics
    [microcontroller.kicad_sch, peripherals.kicad_sch, rjx_training_kit.kicad_sch]
2026-03-06 [RJX]: Custom LD39200 footprint no longer required. Therefore, footprint table is unnecessary.
2026-03-06 [RJX]: Initial footprint assignment. This is subject to further review and analysis.
    [microcontroller.kicad_sch, peripherals.kicad_sch, rjx_training_kit.kicad_sch]
2026-03-06 [RJX]: Updated README.md. Additional markdown files containing information about BOM development and project research stages have been included in the repo.
2026-03-12 [RJX]: Updated load capacitance values
    [microcontroller.kicad_sch]
2026-03-12 [RJX]: Schematic update
2026-03-16 [RJX]: Selected and verified most component footprints. Next task is to properly size the power resistors.
2026-03-19 [RJX]: Replaced the vertical footprint for the JST connector with a horizontal one.
    [peripherals.kicad_sch]
2026-05-21 [RJX]: Removed BOM Checklist and Layout Reference Manual
2026-05-21 [RJX]: Initial netlist and commencement of PCB layout
    [rjx_training_kit.kicad_pcb]
2026-05-21 [RJX]: Schematic, Netlist, and PCB update. Replaced 2-pin crystal with 4-pin passive crystal.
    [microcontroller.kicad_sch, peripherals.kicad_sch, rjx_training_kit.kicad_pcb]
2026-05-21 [RJX]: Deleted the Third_Party directory and kept all 3rd party libraries in the Libs directory for simplicity.
    [rjx_training_kit.kicad_pcb]
2026-05-21 [RJX]: Deleted netlist because it is poor for version control. The PCB is directly updated from the schematic instead of relying on netlists.
    [rjx_training_kit.kicad_pcb]
